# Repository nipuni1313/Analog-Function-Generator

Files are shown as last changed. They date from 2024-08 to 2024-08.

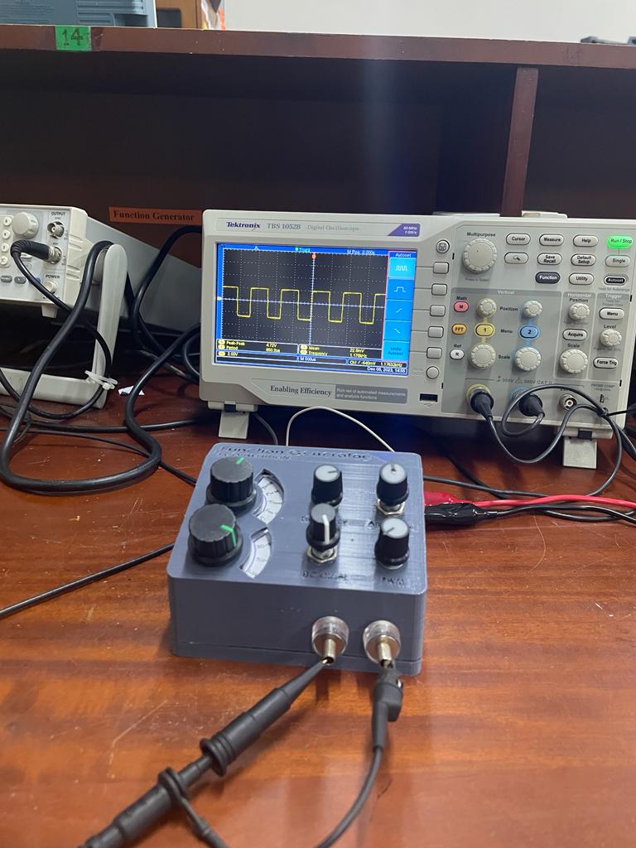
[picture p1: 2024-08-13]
Images/WhatsApp Image 2023-12-06 at 13.45.35_54b62268.jpg

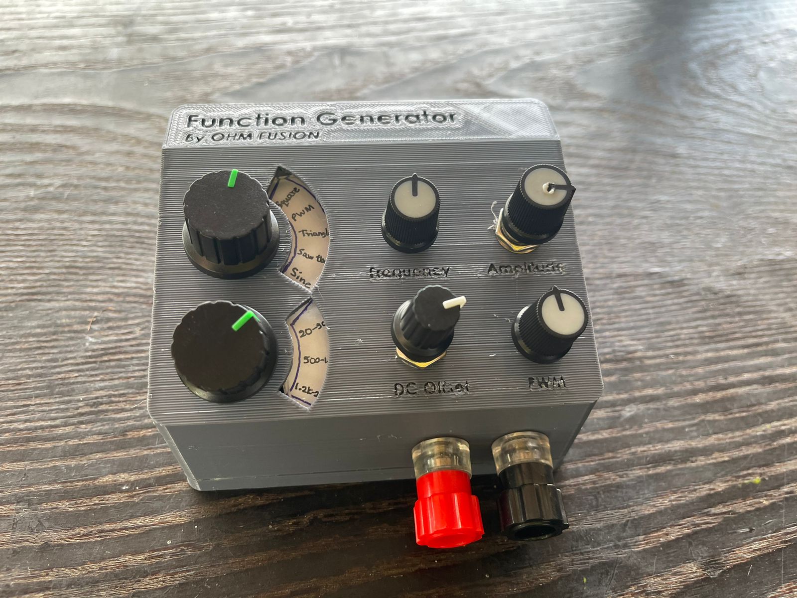
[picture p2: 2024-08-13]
Images/WhatsApp Image 2023-12-06 at 09.40.12_db9edf71.jpg

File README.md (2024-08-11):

# 📡 Analog Function Generator

Function Generator

### 🚀 Project Overview
The Analog Function Generator is a compact and portable device designed for electronic enthusiasts. It generates various waveforms including sine, square, PWM, triangle, and sawtooth waves. With an adjustable amplitude of 0-12V and a frequency range of 20Hz to 20,000Hz, this open-source tool is ideal for testing and development in analog electronics.

### ✨ Features
- **Waveforms**: Sine, Square, PWM, Triangle, Sawtooth
- **Amplitude**: Adjustable 0-12V output
- **Frequency Range**: 20Hz to 20,000Hz
- **Design**: Compact, portable, and built with analog components
- **Open-Source**: Fully documented with schematics and design files

### 📐 Circuit Diagram
Below is the circuit diagram for the Analog Function Generator:

Circuit Diagram

### 🛠️ Components
- **Resistors**: Various
- **Capacitors**: Various
- **Op-Amps**: TL082
- **Potentiometers**: For adjusting amplitude and frequency
- **Power Supply**: 30V

### ⚙️ How It Works
The Analog Function Generator operates using a series of oscillators and filters built with op-amps. The core of the generator is an analog oscillator that produces the base waveform. This waveform is then shaped into the desired output using a combination of filters and amplifiers. The amplitude and frequency are adjustable via potentiometers, allowing for precise control over the output.

### 🚀 Setup & Usage
1. **Build the Circuit**: Follow the circuit diagram to construct the function generator on a breadboard or PCB.
2. **Power the Circuit**: Connect the 30V DC power supply.
3. **Select Waveform**: Use the selector switch to choose between sine, square, PWM, triangle, and sawtooth waves.
4. **Adjust Amplitude & Frequency**: Use the potentiometers to set the desired output amplitude and frequency.
5. **Connect to Oscilloscope**: Test the output waveforms using an oscilloscope to verify the functionality.

### 📊 Results
[Include oscilloscope screenshots or photos of the output waveforms here, showing the different waveforms generated by the device.]

### 🧩 Challenges Faced
- **Stability**: Ensuring the stability of the frequency across the entire range.
- **Component Selection**: Finding the right components to achieve the desired performance within the compact design.
- **Heat Management**: Managing heat dissipation in the compact design.

### 🔄 Future Improvements
- **Extended Frequency Range**: Expanding the frequency range to cover higher frequencies.
- **Digital Control**: Integrating a digital control interface for more precise adjustments.
- **Enhanced Portability**: Reducing the size further to make the device even more portable.

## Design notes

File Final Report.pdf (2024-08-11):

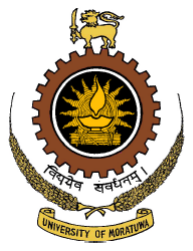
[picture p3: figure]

Department of Electronic & Telecommunication Engineering University of Moratuwa, Sri Lanka.

# Function Generator

Group Members:

210212N | HERATH B.H.M.K.S.B
210215C | HERATH H.M.D.P.
210216F | HERATH H.M.G.N.I.
210205V | HAPUTHANTHRI H.L.N.B.

Submitted in partial fulfillment of the requirements for the module EN 2091 Laboratory Practice and Projects

06.12.2023

Function Generator | 25

## Contents

1 Introduction and Functionality | 2
2 Requirements | 2
3 Calculations and design | 2
4 Changing frequency in regions | 5
5 Selection of components | 6
6 Power supply | 7
7 Push Pull Output with Voltage Buffer | 7
8 | Simulation & Testing | 7
9 Amplitude variation and DC offset | 8
10 PCB Design | 9
11 Enclosure Design | 10
12 Hardware Testing | 12
13 Future improvements | 13
14 Contribution of Group Members | 13
15 References | 13

1

Abstract
In this report, we have outlined the design process for an analog function generator. The entire design was constructed using analog components such as op-amps, transistors, capacitors, resistors, etc. The report provides details on the production of sine, square, triangular, and sawtooth waves, with amplitude variation from 0V to 10V, frequency ranging from 20Hz to 20kHz, and a variable duty cycle for PWM waves from 1% to 99%. Additionally, the report includes PCB designs, enclosure designs, and suggestions for future improvements that can be implemented.

## 1 Introduction and Functionality

In our project, we aimed to design a versatile function generator employing basic analog circuits and components such as transistors, resistors, potentiometers, op-amps, and capacitors. The function generator is intended to produce sine, square, triangular, and sawtooth waves, with amplitude variation from 0V to 10V, frequency ranging from 20Hz to 20kHz, and a variable duty cycle for PWM waves from 1% to 99%. For square wave generation, we utilized an op-amp Schmitt trigger exploiting hysteresis. PWM wave generation involved modulating a triangle waveform through integration of a square wave with a DC offset. Frequency variation was achieved by adjusting resistor and capacitor values. Op-amps, specifically NE5532, were chosen for their high slew rate and sufficient bandwidth. Complementary symmetric transistors and MOSFETs were employed for balanced operation and efficient amplification. Additionally, a dedicated power supply circuit capable of generating a 12V dual power supply was designed to meet the requirements of the op-amps.

## 2 Requirements

The given requirements were met in the design of the function generator.

- Waves: square / triangle / sawtooth / sine
- Amplitude variation: 0V – 10V
- Frequency variation: 20Hz – 20kHz
- Variable duty cycle for PWM wave: 1% - 99%
- Should be able to drive a 50Ω minimum load.

## 3 Calculations and design

### 3.1 Square wave generation

We constructed a square wave generator utilizing an op-amp Schmitt trigger. This device exploits the hysteresis property of the Schmitt trigger, using a positive feedback to generate a square wave. The input triangle wave is applied to the non-inverting terminal of the Schmitt trigger. Initially in a stable state, the trigger transitions when the rising edge of the triangle wave surpasses the upper threshold, causing the output to switch states. Conversely, when the falling edge of the triangle wave crosses the lower threshold, the output reverts to its original state. This process repeats, resulting in the continuous generation of a square wave as the triangle wave oscillates.

2

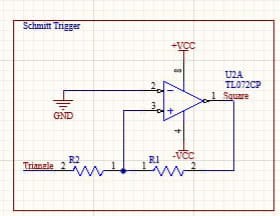
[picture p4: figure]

Figure 1: Schmitt trigger

### 3.2 PWM wave generation

The duty cycle variation is achieved by varying the voltage level between -Vs and +Vs of the noninverting terminal of the integrator. In generating a PWM wave, a triangle waveform, created through integration of a square wave, is modulated by a DC offset. This offset, applied to the non-inverting terminal, shifts the triangular waveform, influencing the duty cycle and producing a precisely controlled PWM output with varied average voltage.

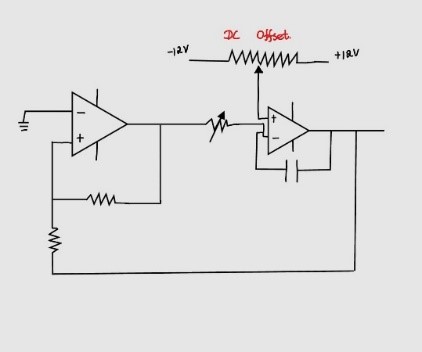
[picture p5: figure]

Figure 2: PWM wave with DC offset

### 3.3 Saw-tooth Wave Generation

To design a sawtooth wave generator, utilize an operational amplifier (op-amp) configured as an inverting amplifier. Employ a Metal-Oxide-Semiconductor Field-Effect Transistor (MOSFET) as a switch in conjunction with the op-amp. Connect a resistor from the input signal to the MOSFET gate, allowing the capacitor to charge through the MOSFET when it is on. Implement a feedback network with resistors to set the gain of the inverting amplifier. This cyclical process results in a sawtooth waveform.

3

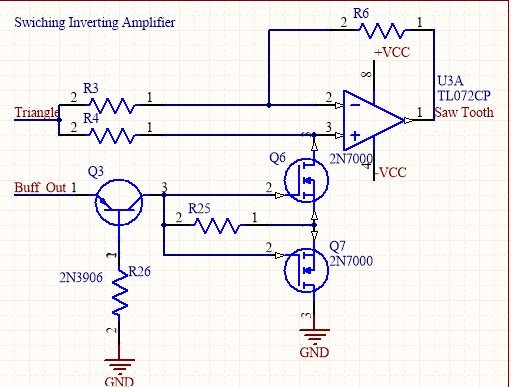
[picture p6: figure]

Figure 3: Saw tooth wave generating circuit

### 3.4 Triangle Wave Generation

Triangle Waves are generated by connecting integrator circuit at the output of schmitt trigger. Let the output of the schmitt trigger is at a +vsat , the integrator continuously integrates the signal until the output voltage reaching a specific threshold level. Upon crossing this threshold, the Schmitt trigger switches its output to -Vsat. The integrator then proceeds to integrate this -Vsat signal for a finite duration. By repeating this process generates a triangular waveform in the circuit.

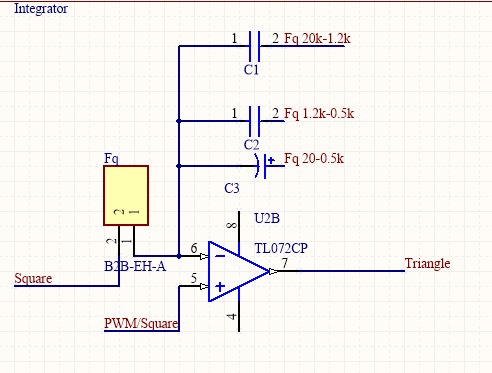
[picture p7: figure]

Figure 4: Designing of triangular circuit

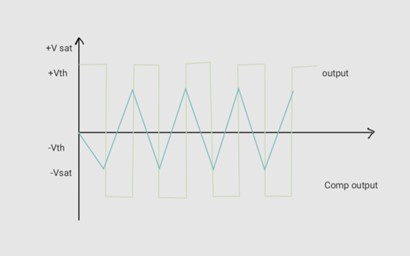
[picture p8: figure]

Figure 5: Triangle wave

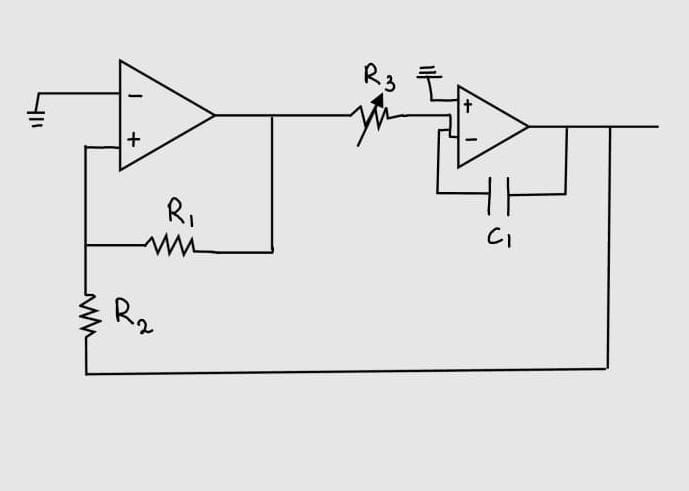
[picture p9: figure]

Figure 6

4

V+ =

R1
R1 + R2

VX +

R2
R1 + R2
Vsat | (1)
V+ = 0 | (2)

Vout1 = −

R2
R1
- Vsat | (3)

Vout2 =

R2
R1
- Vsat | (4)

VPP = 2

R2
R1
- Vsat | (5)

VPP = −

1
R3C1

Z T /2

0

Vin(t) dt | (6)

f =

R1
4R3R2C1

(7)

Amplitude

VPP = 2

R2
R1
- Vsat | (8)

frequency

f =

R1
4R3R2C1

(9)

## 4 Changing frequency in regions

The frequency is varied by changing a resistor value and capacitor value. We have used four capacitors (connected to the integrator) to cover the range of 20Hz to 20kHz. To finely change frequencies in each region, a variable resistor was used

Frequency range | capacitor value
20Hz - 500Hz 500Hz - 1.2kHz 1.2kHz - 20kHz | 1µF 100nF 10µF

Table 1: capacitor values needed for each range

Figure 7: Multisim Schematic Diagram | Figure 8: Capacitor bank

5

Figure 9: Schmitt trigger

V+ =

R1
R1 + R2

VX +

R2
R1 + R2
Vsat | (10)
V+ = 0 | (11)

Vout1 = −

R2
R1
- Vsat | (12)

Vout2 =

R2
R1
- Vsat | (13)

VPP = 2

R2
R1
- Vsat | (14)
V+ = 0 | (15)

VPP = −

1
R3C1

Z T /2

0

Vin(t) dt | (16)

f =

R1
4R3R2C1

(17)

## 5 Selection of components

### 5.1 Op-Amp selection

For all implementations, the op-amps that were used were NE5532. NE5532 op-amp has a slew rate of 8V/µs. Such a high slew rate is needed since sawtooth and square wave forms becomes distorted in higher frequencies. The bandwidth of the Op-amp is 10MHz. It is enough to generate the frequency range required (20Hz-20kHz).

### 5.2 Transistor selection

Two complementary symmetric transistors, TIP31C (npn) and TIP32C (pnp), were used in the push-pull circuit to achieve balanced operation, reducing distortion and enabling efficient amplification of both the positive and negative halves of the input signal. Both transistors have a maximum collector current of 3A; since the circuit should support a maximum current of 200mA (10V/50Ω), these transistors were deemed suitable for the circuit. In the generation of the sawtooth wave, a switching circuit was implemented using two 2N7000 MOSFETs and a 2N3906 (pnp). The maximum collector current of the 2N3906 is 200mA, which is within the acceptable range and does not exceed the circuit’s maximum supported current.

6

## 6 Power supply

Since each op-amp requires a 12V dual power supply, a power supply circuit capable of generating a dual 12V power supply was designed. The power supply is designed using both a negative voltage regulator and a positive voltage regulator, along with an op-amp buffer and a push-pull circuit.

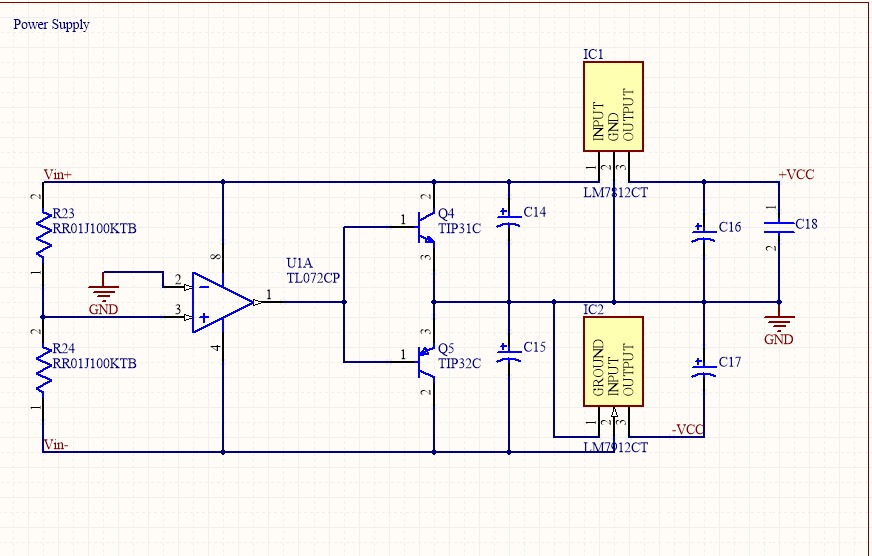
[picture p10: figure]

Figure 10: Power supply

## 7 Push Pull Output with Voltage Buffer

The amplifier output is sent to a buffer with a push-pull output stage designed to enhance current drive, utilizing a complementary pair of NPN and PNP transistors. The op-amp buffer removes

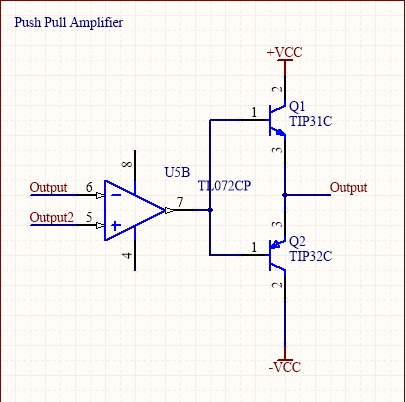
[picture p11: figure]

Figure 11: circuit for push pull

crossover distortion in the push-pull amplifier. In a standard push-pull configuration, when the instantaneous amplitude is small, both transistors remain off, leading to distortion. However, in this circuit, the absence of negative feedback in such situations causes the op-amp output to saturate. As a result, one of the transistors turns on, preventing distortion. The buffer also maintains a unity gain.

## 8 Simulation & Testing

Creating electronic circuits involves a challenging and time-consuming process. To guarantee the final product aligns with the desired specifications, it is crucial to simulate and test the circuit before progressing to the manufacturing phase of the printed circuit board (PCB). The circuit design was

7

simulated and validated for functionality using the National Instruments (NI) Multisim software. After simulating and optimizing the circuit’s performance, it was implemented on a breadboard, and waveform analysis was conducted with an oscilloscope. This visual representation of the circuit’s signals enabled the identification of any disparities between the simulated and actual results.

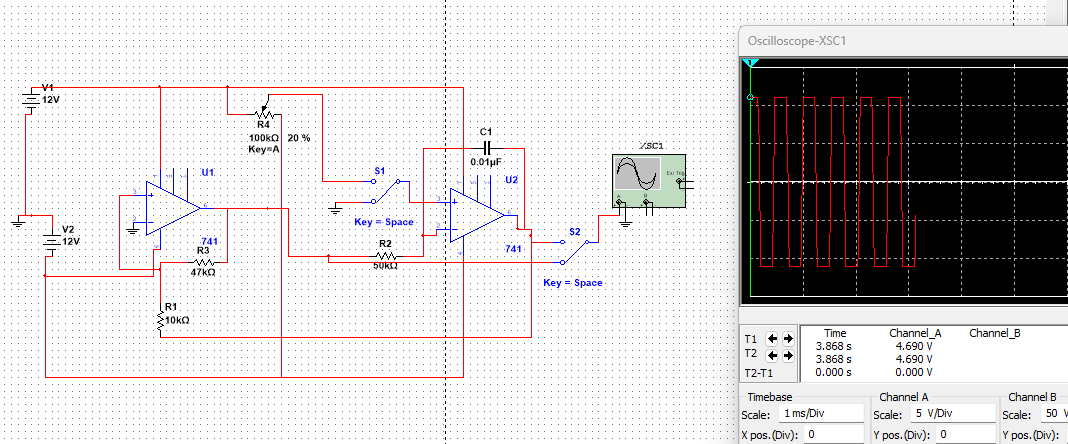
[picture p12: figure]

Figure 12: Simulation in multisim

## 9 Amplitude variation and DC offset

In the common amplifier, a summing amplifier with DC offset to efficiently handle input signals. This summing amplifier was designed to sum multiple input waveforms while accounting for a specific DC offset, enhancing the amplifier’s adaptability. Specifically for square wave signals, it integrated an inverting amplifier as a gain reduction stage. This additional layer of gain reduction ensures that the square wave signal is appropriately shaped and scaled before being routed to the common amplifier. a common inverting amplifier which will allow amplitude variation between 0-12 V. The wave amplitudes are adjusted to the same level before sending through this amplifier to maintain consistency.

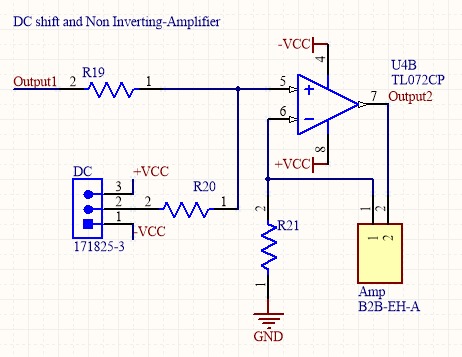
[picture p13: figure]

Figure 13: Amplitude and DC offset variation circuit

### 9.1 Amplitude variation of square wave

Since the square wave generated by the Schmitt trigger oscillates between +12V and -12V, we have utilized an inverting amplifier to enable variation of the amplitude in the range of 0V to 10V by attenuating the wave.

8

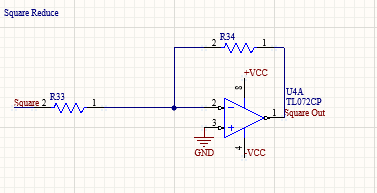
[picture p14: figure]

Figure 14: Amplitude and DC offset variation circuit

## 10 PCB Design

PCB design has done using Altium Designe. It was designed as a double layer PCB.

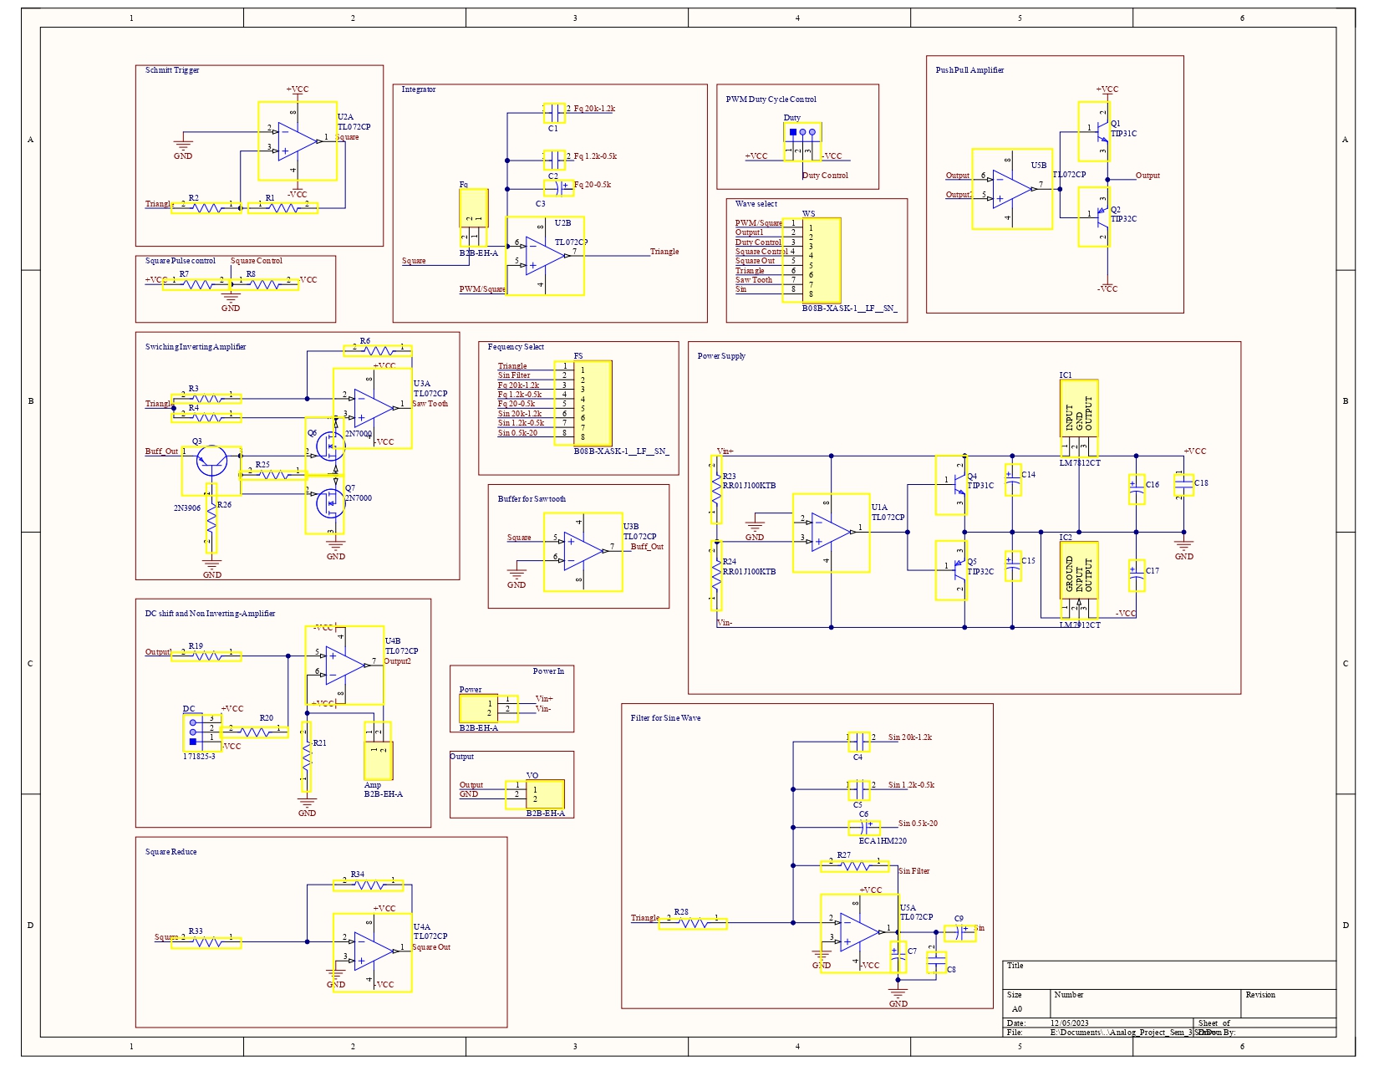
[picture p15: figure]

Figure 15: PCB Schematic

9

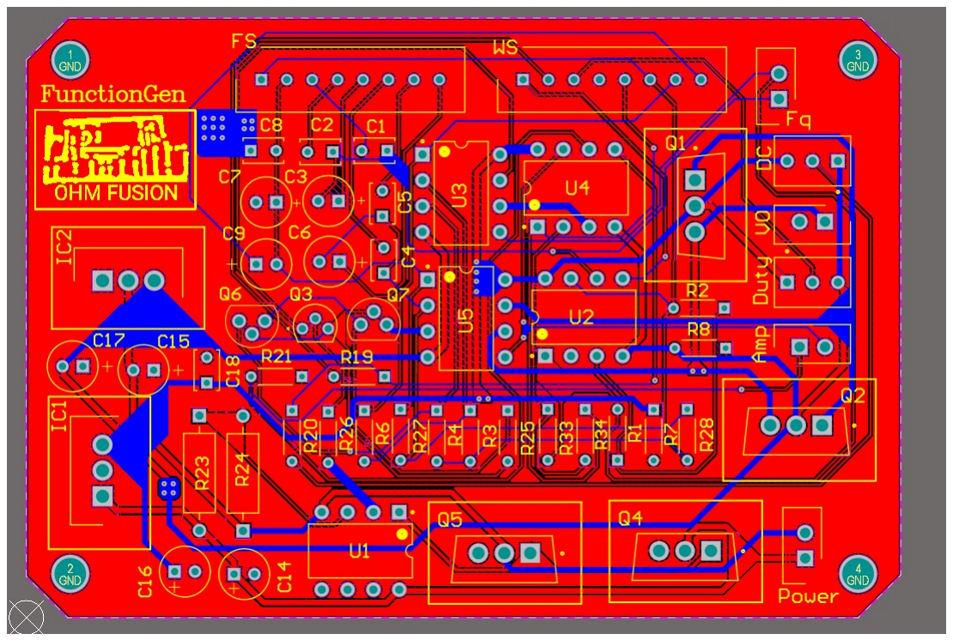
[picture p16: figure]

Figure 16: PCB routing

## 11 Enclosure Design

Enclosure design was created using Solidworks software.

10

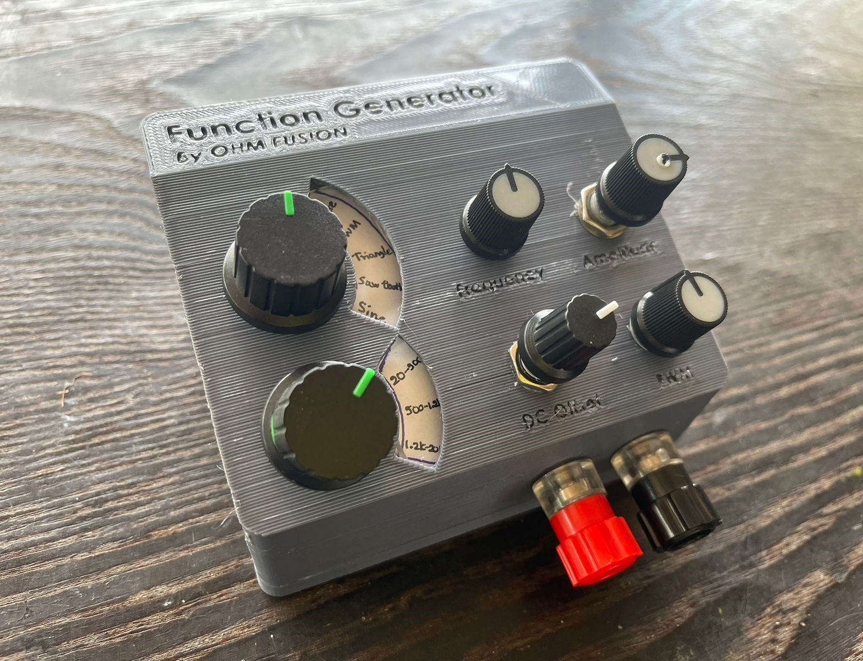
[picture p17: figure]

Figure 17: Enclosure

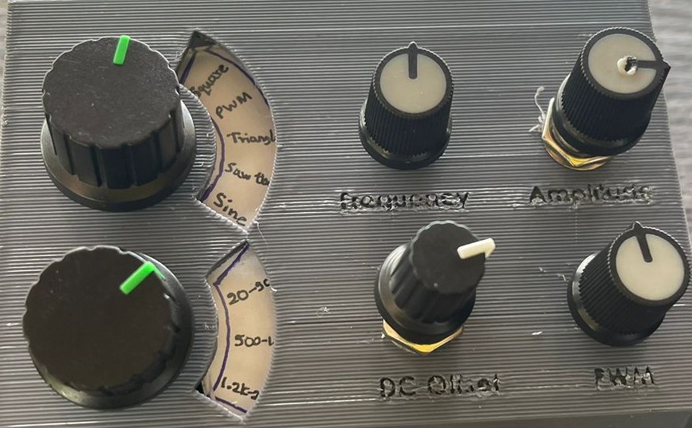
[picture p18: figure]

Figure 18: User interface

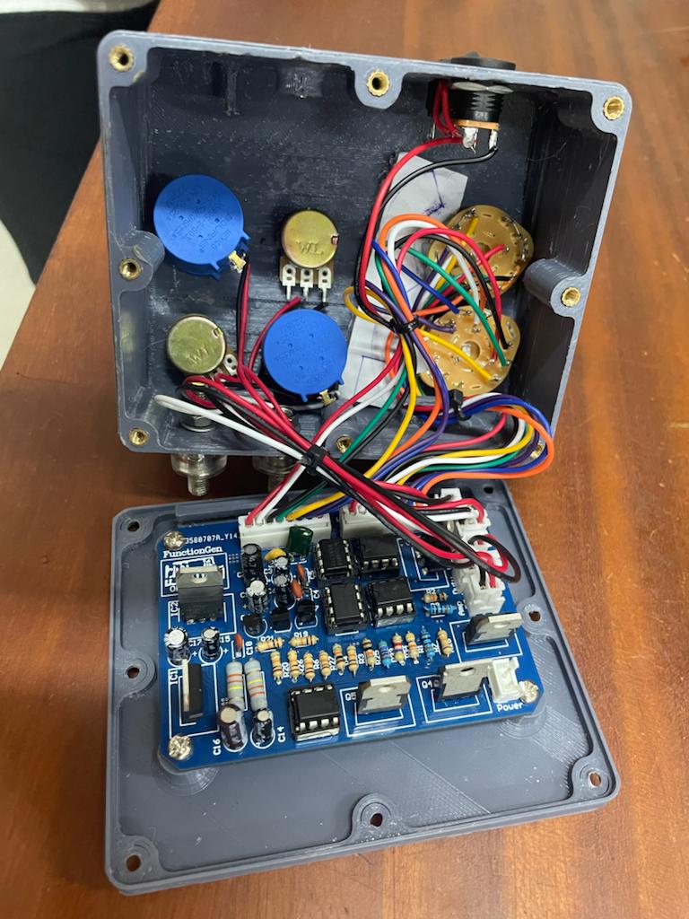
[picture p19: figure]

Figure 19: Assembly

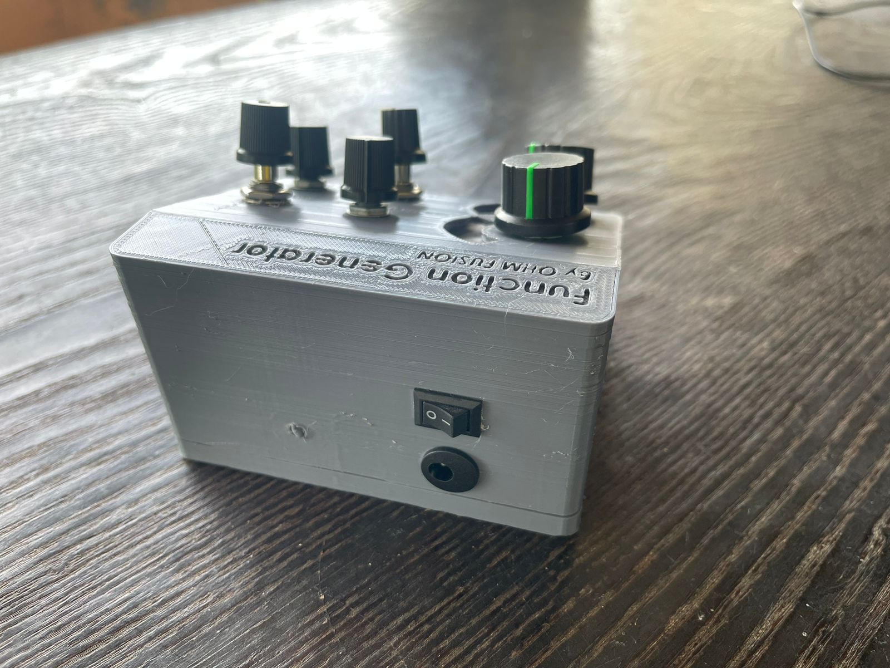
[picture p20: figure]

Figure 20: Enclosure

11

## 12 Hardware Testing

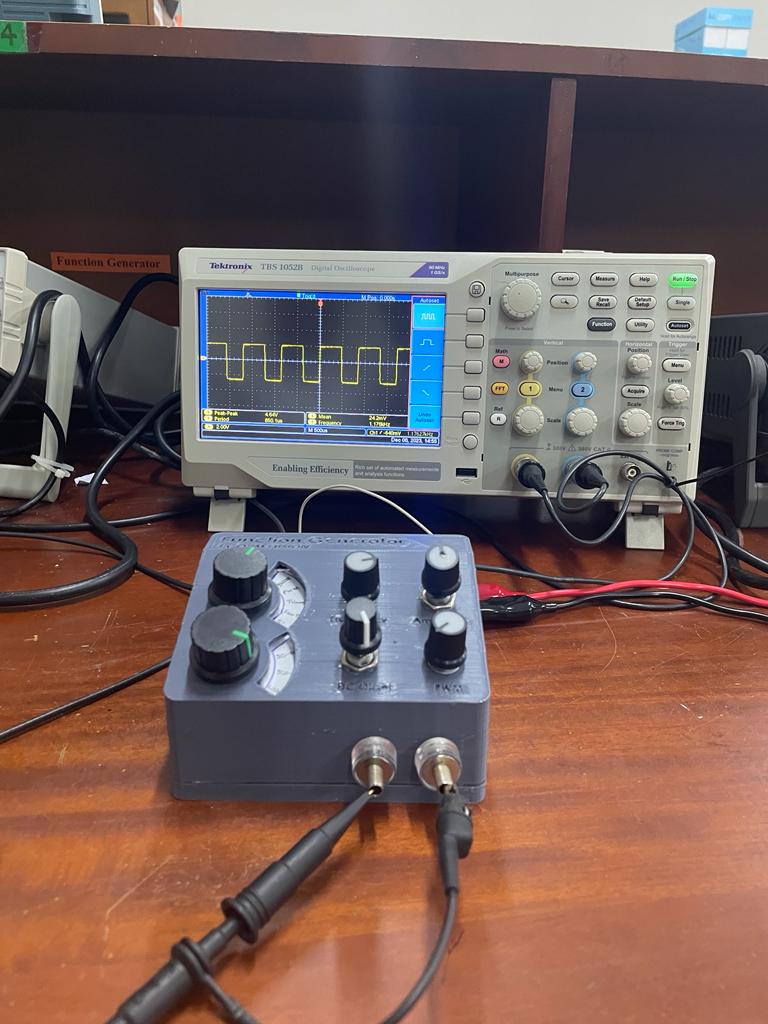
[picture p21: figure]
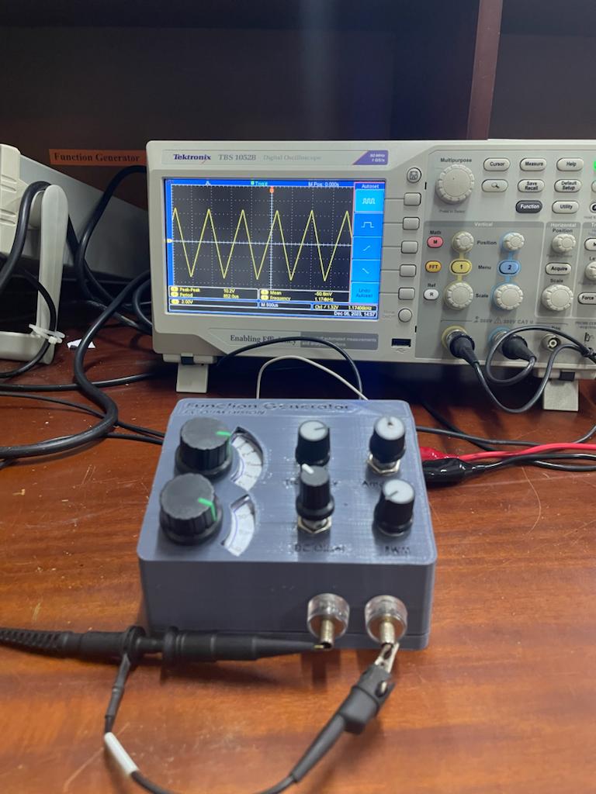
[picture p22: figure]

(a) Square Wave | (b) Triangle wave

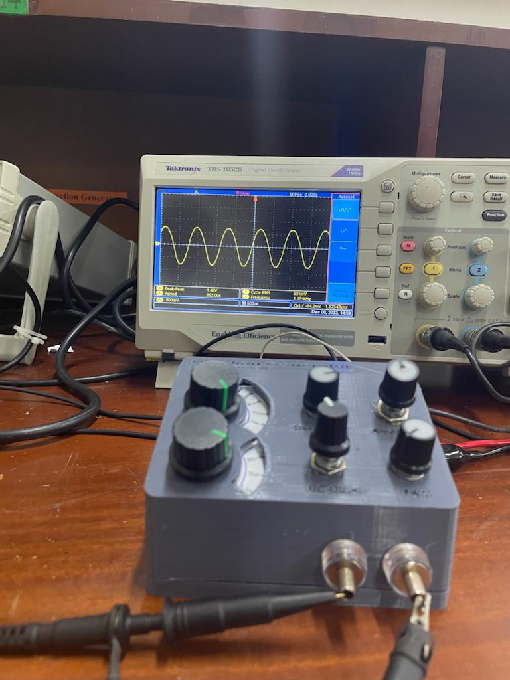
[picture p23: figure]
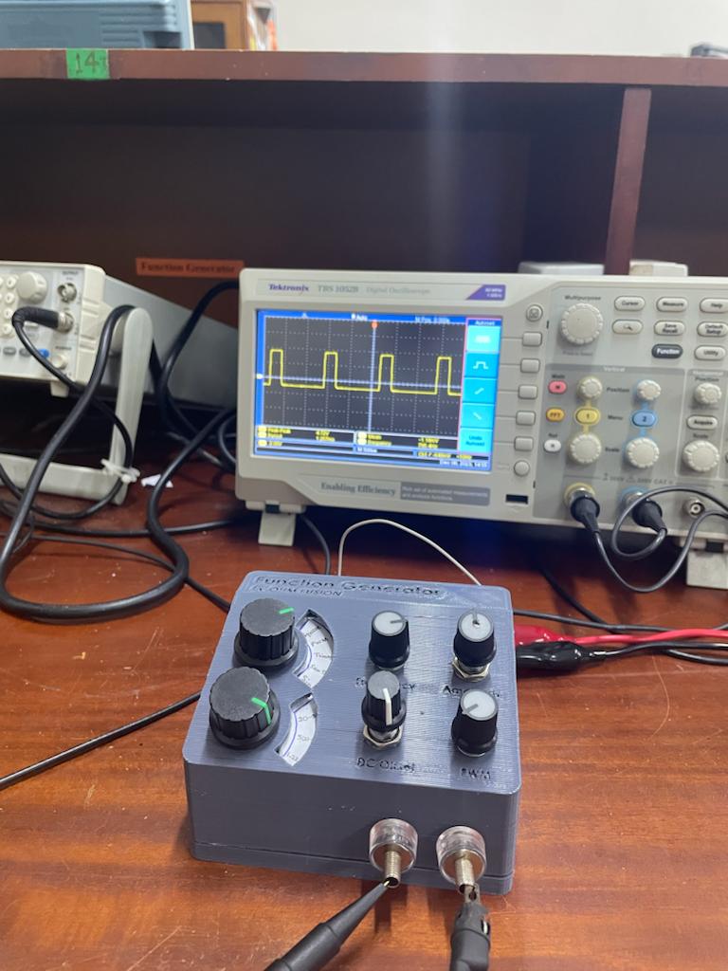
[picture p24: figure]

(c) Sine | (d) PWM wave

12

## 13 Future improvements

In our project, we encountered distortion in the generated sawtooth wave. While this issue could have been addressed through additional testing, unfortunately, time constraints prevented us from doing so. In the generation of the sine wave, we employed a low-pass filter. However, a more effective approach would have involved using higher-order filters to completely eliminate any potential further distortions in the sine wave.

## 14 Contribution of Group Members

- 210212N: Prototyping, Assembly
- 210215C: Enclosure design, Documentation
- 210216F: Prototyping, Documentation
- 210205V: PCB design, Enclosure design, Assembly

## 15 References

1. [? ]-Function generator(https://en.wikipedia.org/wiki/Function_generator)
2. [? ] - How to Build Your Own Function Generator Using Analog Devices’ AD9833.(https://www.allaboutcircuits.com/projects/how-to-DIY-waveform-generator-analog-devices-ad9833-ATmega328p/)
3. [? ] - DIY Function/Waveform Generator.(https://www.instructables.com/DIY-FunctionWaveform-Generator/)
4. [? ] - How to Build a Simple Function Generator with an LM324 Op Amp Chip.(http: //www.learningaboutelectronics.com/Articles/Function-generator-circuit.php)
5. [? ] - Analog Function Generator.(https://www.instructables.com/Function-Generator/)
6. [? ] - 10 Useful Function Generator Circuits Explained.(https://www.homemade-circuits.com/simple-function-generator-circuit/) (https://www.homemade-circuits.com/simple-function-generator-circuit/)
7. [? ] - Triangular Wave Generator Using Op amp.(https://www.eeeguide.com/triangular-wave-generator-using-op-amp/)
8. [? ] - Precision Triangular-Wave Generator Uses a Single IC.(https://www.analog.com/en/technical-articles/precision-triangularwave-generator-uses-a-single-ic.html) (https://www.analog.com/en/technical-articles/precision-triangularwave-generator-uses-a-single-ic.html)
9. [? ] - Electronics Fundamentals: Circuits, Devices and Applications.(https://www.amazon.com/Electronics-Fundamentals-Circuits-Devices-Applications/dp/0135072956) (https://www.amazon.com/Electronics-Fundamentals-Circuits-Devices-Applications/dp/0135072956)

13

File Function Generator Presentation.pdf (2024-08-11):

# Function Generator

# Introduction

That are used to generate different types of electrical waveforms over a wide range of frequencies.

The most common waveforms produced by the function generator are the ”Sine wave, Square wave , Triangular wave and Sawtooth wave”. Another feature included on many function generators is the ability to add a DC offset.

Function generators were designed using basic analog circuits that incorporated operational amplifiers, resistors, and capacitors.

These analog function generators operated by creating waveforms through a feedback loop and subsequently filtering the output to attain the intended waveform.

We are designing a function generator for our project using only transistors, resistors, potentiometers, op Amps and capacitors. In this report, the different techniques which were used to generate waveforms and change the characteristics of the wave forms will be described.

# Square wave generator

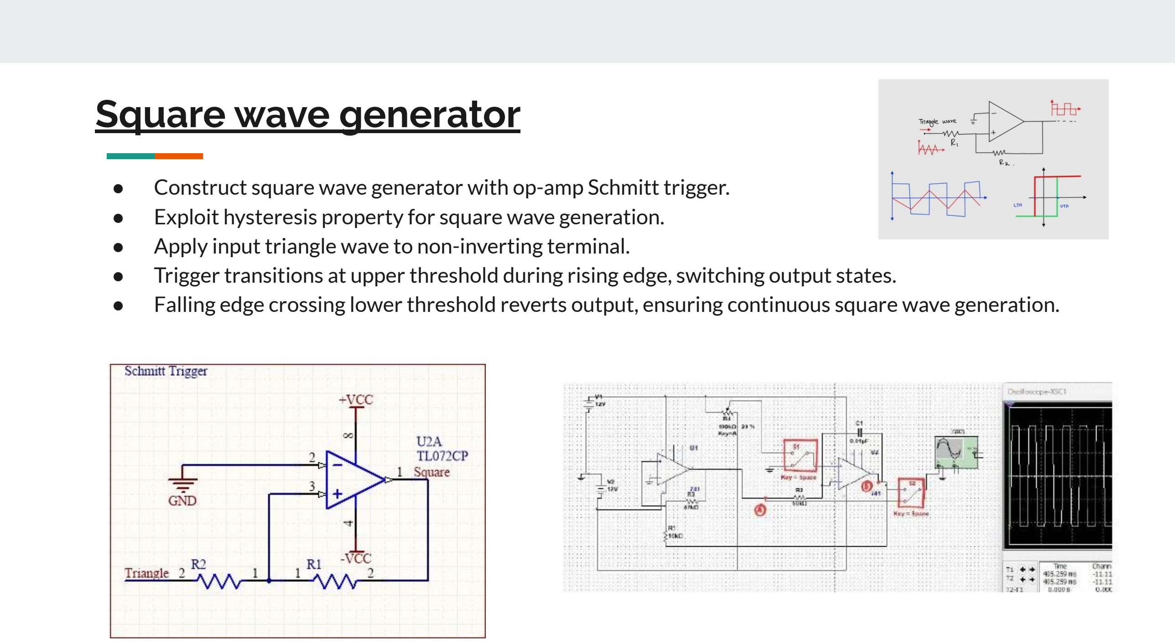
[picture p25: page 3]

- Construct square wave generator with op-amp Schmitt trigger.
- Exploit hysteresis property for square wave generation.
- Apply input triangle wave to non-inverting terminal.
- Trigger transitions at upper threshold during rising edge, switching output states.
- Falling edge crossing lower threshold reverts output, ensuring continuous square wave generation.

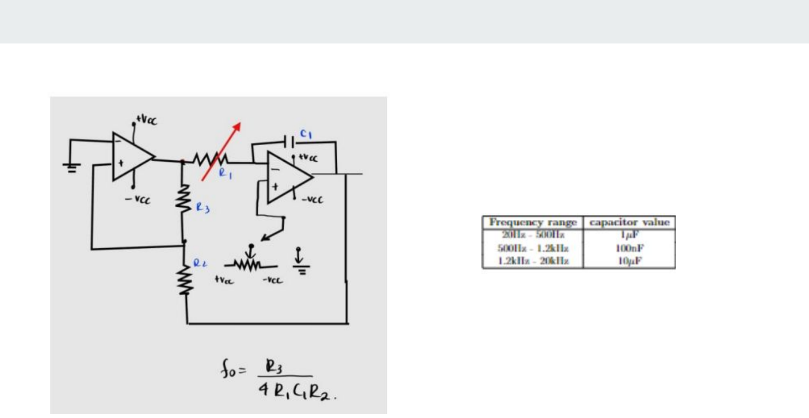
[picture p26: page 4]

# PWM generator

- The non inverting input of the second op amp is connected to a variable resistor, giving a DC voltage to the input.
- The signal is taken from position A.
- The duty cycle of the PWM signal is set by the DC voltage at the non-inverting input of the integrator.
- By changing this DC voltage, you can vary the duty cycle of the PWM waveform.
- The frequency of the PWM signal is determined by the frequency of the triangle wave.



# Triangle generator


- Triangle Waves are generated by connecting integrator circuit at the output of schmitt trigger.
- This is created by integrating the square signal by the integrating circuit containing the second op amp and capacitor.
- A continuous triangle signal is generated.

- By adding a low pass filter to triangle wave form we generated the sine wave
- C7 & C8 capacitors use to improve stability

# Sine wave generator


- Design a sawtooth wave generator using an op-amp as an inverting amplifier.
- Utilize a MOSFET as a switch, allowing the capacitor to charge through the MOSFET.
- Implement a feedback network to set the inverting amplifier gain.
- For a common amplifier, use a summing amplifier with DC offset to efficiently handle input signals.
- Integrate an inverting amplifier for gain reduction in shaping square wave signals before routing to the common amplifier.

# Sawtooth generator


# Amplification circuit with DC offset


# PCB: using Altium


# Enclosure: using SolidWorks

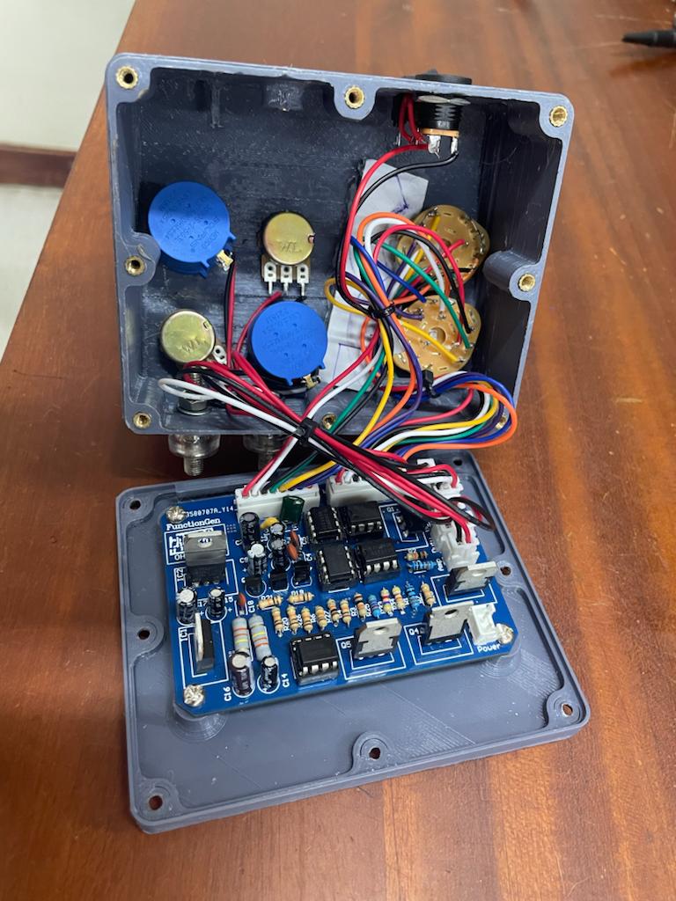
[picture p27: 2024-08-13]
Images/WhatsApp Image 2023-12-06 at 13.48.49_54171d3b.jpg

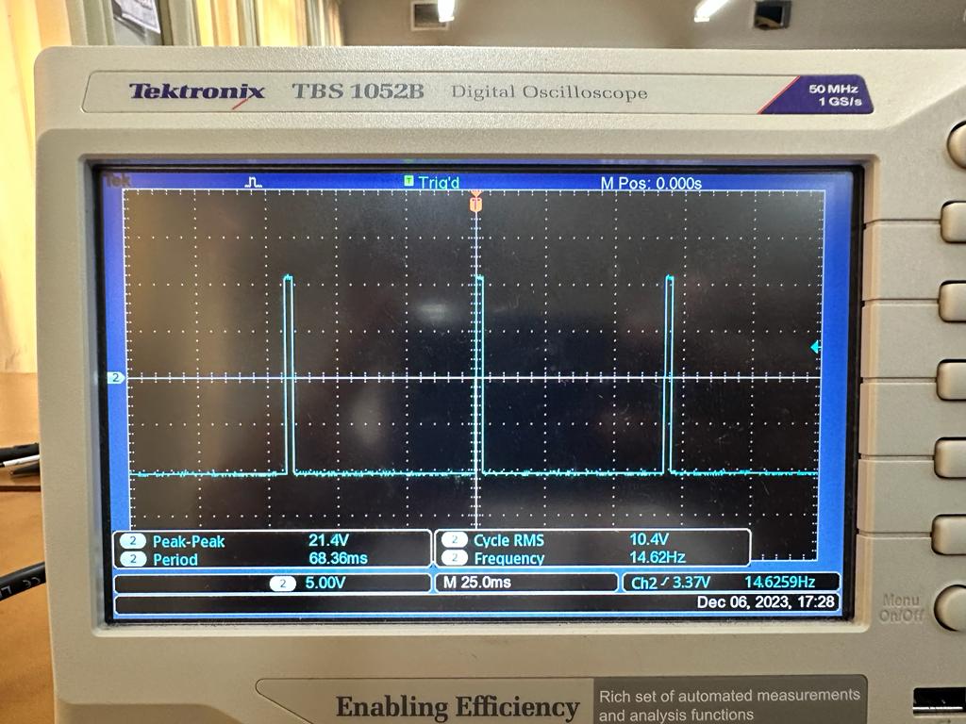
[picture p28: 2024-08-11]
Physical Implimentation/PWM Wave (1% Duty).jpg

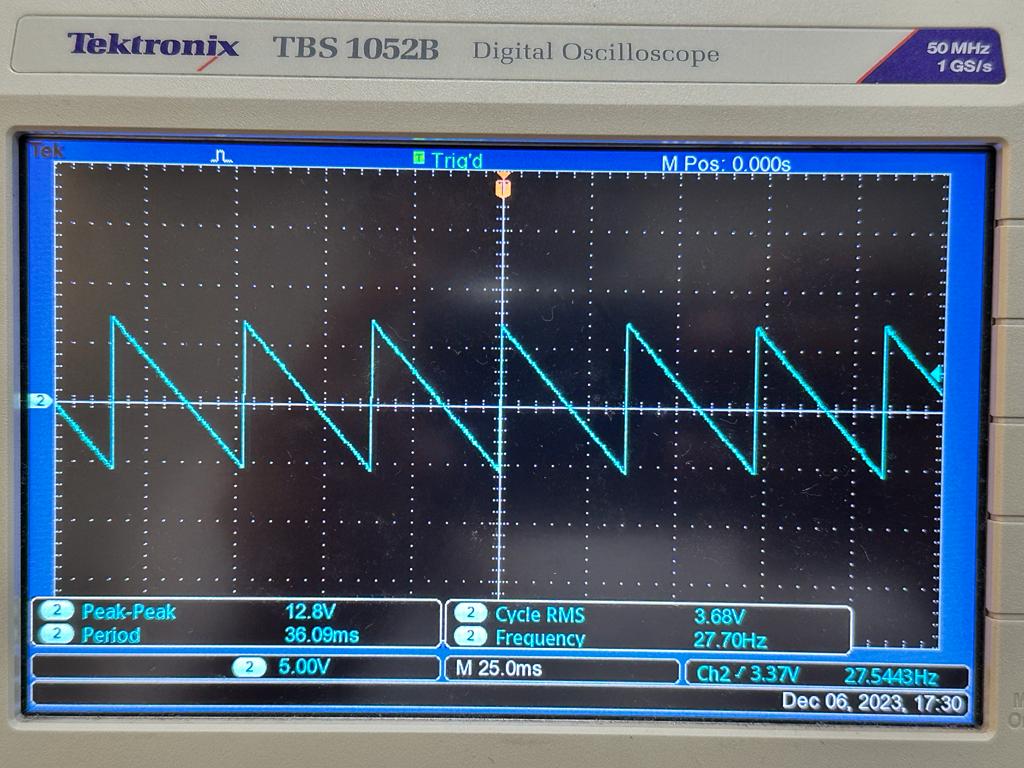
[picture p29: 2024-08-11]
Physical Implimentation/Saw Tooth Wave.jpg

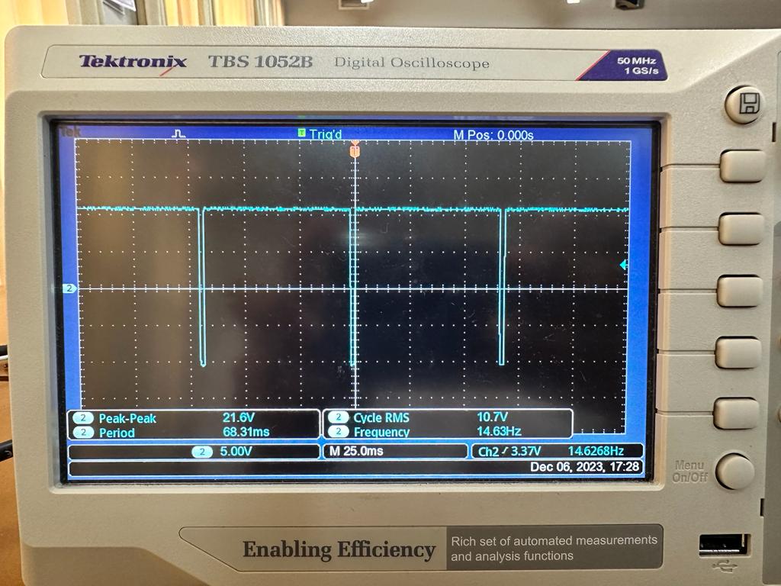
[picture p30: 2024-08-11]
Physical Implimentation/PWM Wave (99% Duty).jpg
